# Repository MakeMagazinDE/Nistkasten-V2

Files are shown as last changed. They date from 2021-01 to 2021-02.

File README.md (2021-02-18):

GitHub Logo

Maker Media GmbH
*** 

# Nistkasten-V2
mit Infrarot-Kamera und Klimasensor

### Mit diesem Nistkasten beobachten Sie Vögel beim Nestbau und Brüten durch eine Infrarot-Kamera, nehmen Videos und Bilder auf und messen Temperatur und Luftfeuchtigkeit im Inneren.

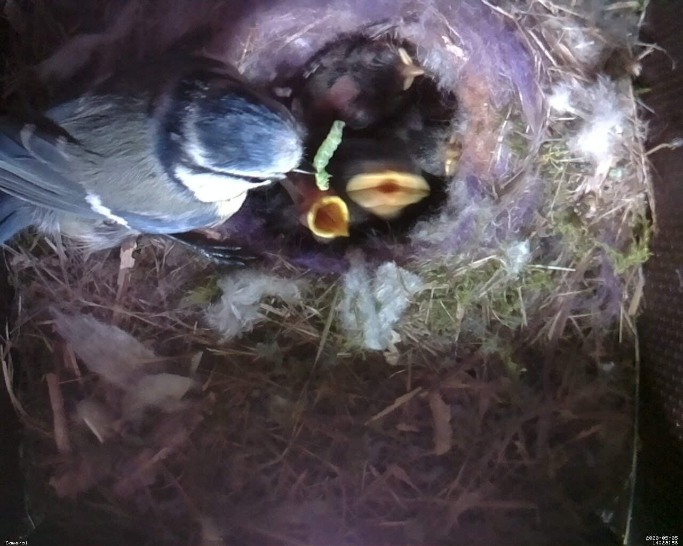
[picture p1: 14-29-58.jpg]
 

Den vollständigen Artikel mit der Bauanleitung gibt es in der **[Make-Ausgabe 1/21 ab Seite 24](https://www.heise.de/select/make/2021/1/2020408465876482831)** zu lesen. 

Lesen Sie bei Problemen bitte die im Ordner [Hinweise](https://github.com/MakeMagazinDE/Nistkasten-V2/blob/main/Hinweise/Problembehebung.md) gespeicherten Dateien.

Achtung: Unter [Software](https://github.com/MakeMagazinDE/Nistkasten-V2/blob/main/Software/Installationsbefehle.txt) finden Sie die Datei mit den Installationsbefehlen. Diese Befehle können Sie per Kopieren und Einfügen zeilenweise übernehmen und vom Raspberry abarbeiten lassen. So vermeiden Sie Mißverständnisse mit Zeilen, die im Magazin wegen Überlänge umgebrochen wurden.

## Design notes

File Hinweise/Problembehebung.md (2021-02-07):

Sollte der Raspberry Zero nach kurzer Zeit kein Kamerabild mehr liefern oder ständig neu booten oder ist das gezeigte Bild überbelichtet,
dann leuchten die IR-LEDs zu stark und nehmen zuviel Strom auf. Wird hingegen bei Tageslicht das Bild des Nestkasten-Inneren plötzlich schwarz, schalten die LEDs zu früh ab.
In beiden Fällen müssen Sie die LEDs mit den Trimmer auf ihren Platinen eingestellen.

Stellen Sie den Trimmer einer der beiden LED so ein, dass sie auch bei völliger Dunkelheit (zugehaltenem Lichtsensor) nicht einschaltet. 
Das Einschalten kann man an einem schwachen roten Glimmen erkennen.

Den Trimmer der anderen LED stellen Sie so ein, dass die LED bei normaler Tageslicht-Zimmerbeleuchtung und offenem Lichtsensor eingeschaltet ist und daher schwach rot glimmt.

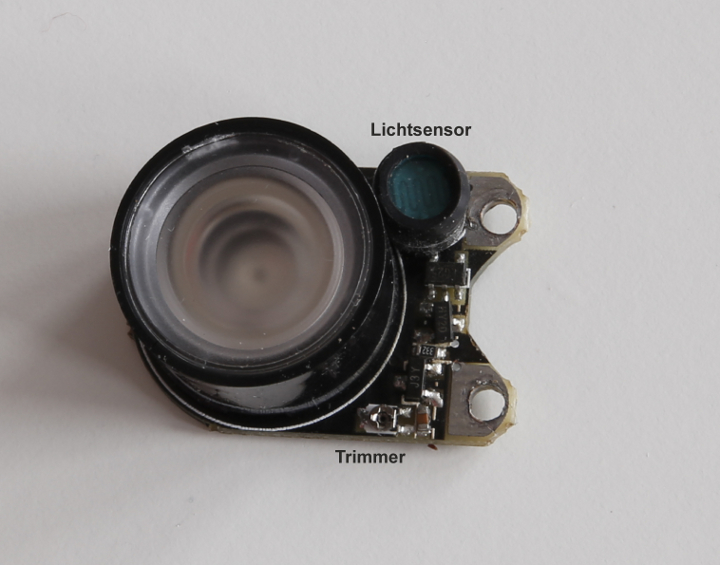
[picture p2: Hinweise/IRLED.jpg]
 

Booten Sie danach den Raspberry erneut, da sich beim Bootvorgang die Kamera auf die Lichtverhaltnisse einstellt.

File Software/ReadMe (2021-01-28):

Befehle bitte einzeln per Copy & Paste in die Konsole übertragen und ausführen.

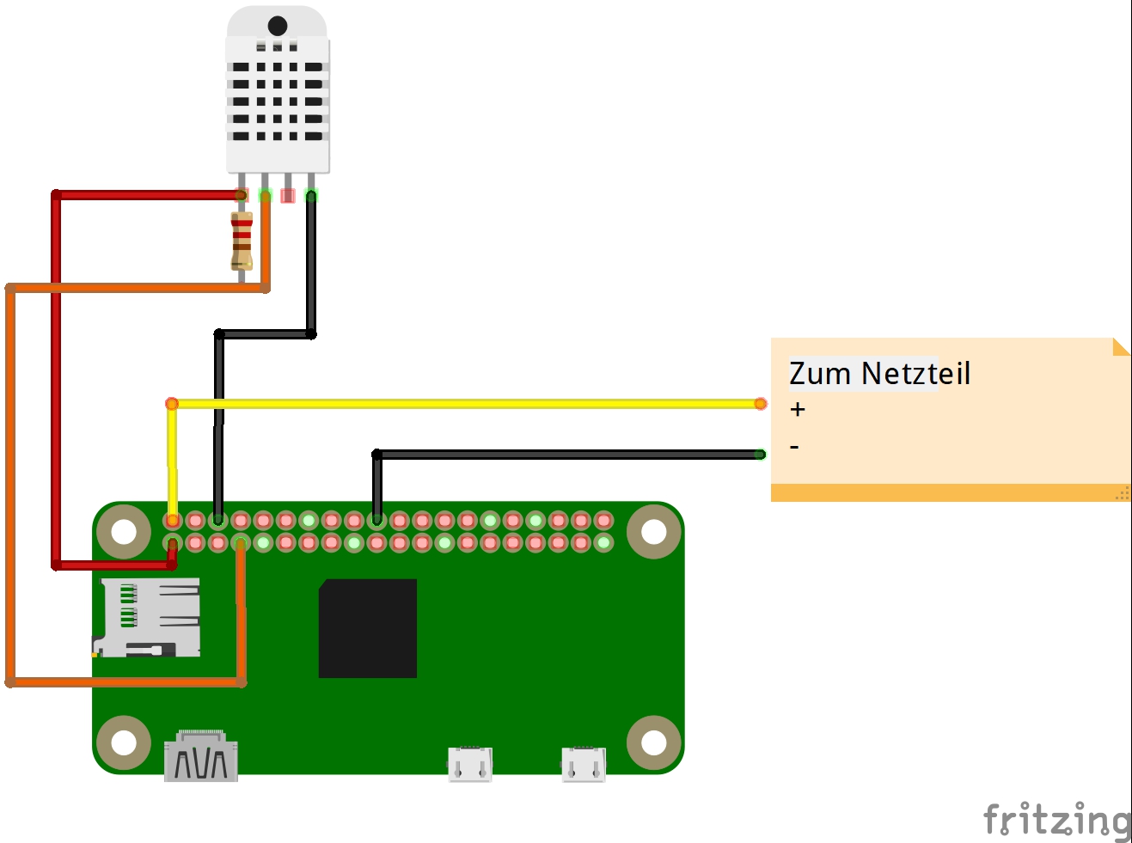
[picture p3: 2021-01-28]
Schaltplan/NistkastenV2.jpg

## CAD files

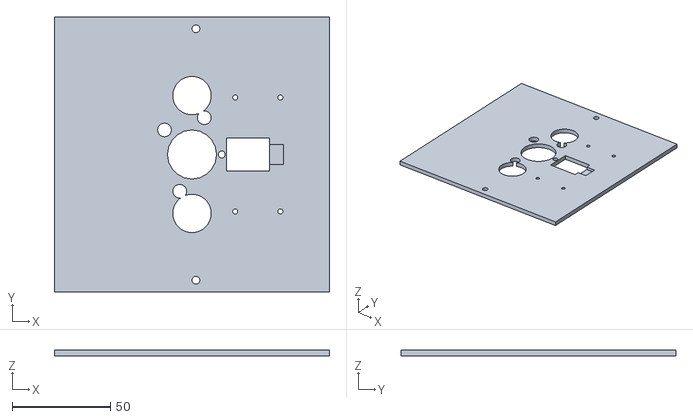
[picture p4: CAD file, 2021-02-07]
Konstruktionsdateien/Nistkasten_Platte.stl
140.0 x 140.0 x 3.00

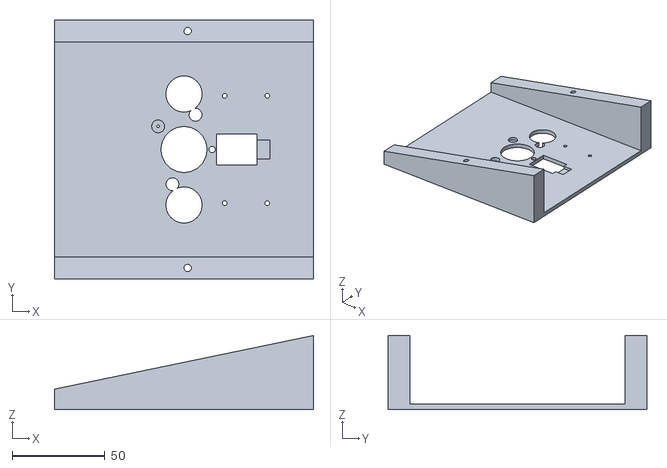
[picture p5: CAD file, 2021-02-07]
Konstruktionsdateien/Nistkasten.stl
140.0 x 140.0 x 40.0

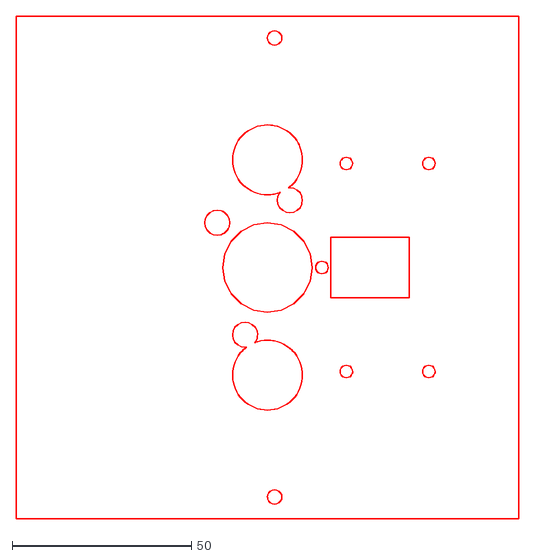
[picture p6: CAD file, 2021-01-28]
Konstruktionsdateien/Zeichnung-1.dxf
140.0 x 140.0

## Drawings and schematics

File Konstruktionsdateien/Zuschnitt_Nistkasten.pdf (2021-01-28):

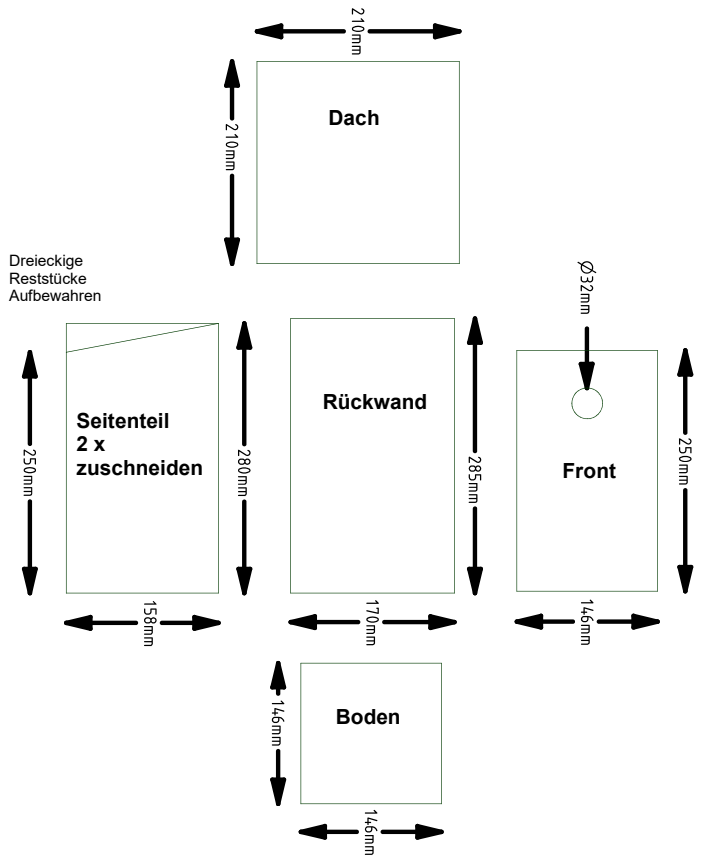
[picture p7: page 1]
Dach; Seitenteil 2 x; zuschneiden; Front; Rückwand; Boden; Dreieckige Reststücke Aufbewahren

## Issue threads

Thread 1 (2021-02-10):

Wrong command

schaeuzerle, 2021-02-10:
https://github.com/MakeMagazinDE/Nistkasten-V2/blob/7462c97816c53f3762aeb029a878e4779167e04f/Software/Installationsbefehle.txt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

should be
`cp /usr/local/share/motioneye/extra/motioneye.systemd-unit-local /etc/systemd/system/motioneye.service`

MasterPMax, 2021-03-02:
Hallo,
ich habe ebenfalls ein Problem bei der Installation der Software.

Nach dem Befehl bekomme ich folgende Fehlermeldung:

```
pi@raspberrypi:~ $ sudo mkdir -p /etc/motioneye
pi@raspberrypi:~ $ sudo cp /usr/local/share/motioneye/extra/motioneye.conf.sample /etc/motioneye/mot                          ioneye.conf
cp: cannot stat '/usr/local/share/motioneye/extra/motioneye.conf.sample': No such file or directory
pi@raspberrypi:~ $ sudo mkdir -p /var/lib/motioneye
pi@raspberrypi:~ $ sudo cp /usr/local/share/motioneye.systemd-unit-local /etc/systemd/system/motioneye.service
cp: cannot stat '/usr/local/share/motioneye.systemd-unit-local': No such file or directory
pi@raspberrypi:~ $ sudo cp /usr/local/share/motioneye/extra/motioneye.systemd-unit-local /etc/systemd/system/motioneye.service
cp: cannot stat '/usr/local/share/motioneye/extra/motioneye.systemd-unit-local': No such file or directory
```
Ich habe auch schon den korrigierten Befehl von oben probiert, ebenfalls ohne Erfolg.
Kann mir hier jemand weiterhelfen?
Vielen Dank!

Gruß MasterPMax

torth, 2021-03-02:
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

hi, ist das Verzeichnis /usr/local/share/motioneye überhaupt vorhanden, oder ist eventuell der Befehl "sudo pip install motioneye" mit einem "_Killed_" abgebrochen? Falls dies zutreffen sollte, dann führe folgenden Befehl aus und mache danach normal weiter:

**_sudo apt-get install python-pillow_**

MasterPMax, 2021-03-02:
Hy,
vielen Dank das wars! Der letzte Punkt collecting pillow war tatsächlich mit Killed abgebrochen.
Jetzt klappt es auch!

noworrries, 2021-03-14:
Selbes Problem, da das "killed" ohne Trennzeichen in der letzten Zeile angefügt wirt, hatte ich es übersehen.
Eine Alternative ist die Installation über
`sudo pip --no-cache-dir install motioneye`
Danke

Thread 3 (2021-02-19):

Platte

charligel, 2021-02-19:
Kann es sein, dass die Aussparungen für die Helligkeitssenoren auf der 3D-Druck-Platte mit Abstand Deckeö verkehrt angebracht sind und damit eine Montage nicht möglich ist?

steffenknott, 2021-02-21:
Ja, das kann ich bestätigen. Ich habe versuchsweise im Slicer das Modell gespiegelt und neu gedruckt, das scheint zu funktionieren.

schaeuzerle, 2021-02-21:
Ja, ist mir auch aufgefallen, nachdem ich es gedruckt habe... Hab einen Fork erstellt, darin liegt nun ein gespiegeltes STL, leicht verschobener Kameraposition und Halterung für einen Raspberry 3B, wenn jemand Interesse hat

Lumixnick, 2021-03-01:
Hallo ist mir auch aufgefallen und ich hab sie kurzerhand umdesigned.
Hier meine STL von gerade. Hoffe ich hab mich nirgends vermessen, meine RasPI liegt auch einfach flach auf, benötige keinen USB-HUB.
[Nistkasten v2_gespiegelt.zip](https://github.com/MakeMagazinDE/Nistkasten-V2/files/6063810/Nistkasten.v2_gespiegelt.zip)

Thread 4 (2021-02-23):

IR-Beleuchtung

avanc, 2021-02-23:
Kann es sein, dass es zwingend notwendig ist, dass der Innenraum dunkel ist?
Ich habe einen Nistkasten in Kiefer aufgebaut. und auch wenn nur eine IR-LED aktiv ist, ist das Bild überbelichtet weiß...

Ich bin mir nicht sicher, ob ich die Sensoren richtig verstanden habe. Wenn ich den Sensor an der Kamera verdecke, hätte ich das Klacken des Filters erwartet und das das Bild dann rötlich ist. Jedoch passiert dies nicht. Nur im Kasten kalckert der Filter hin und her. Jedoch mit dem Problem der Überbelichtung...

torth, 2021-03-19:
hallo zusammen,
kann mir jemand einen Tipp geben, wie ich die IR-LED am besten einstellen kann? Der Trimmregler hat gefühlt in beide Richtungen keinen Anschlag. Eine LED habe ich wie in der Problembeschreibung, zunächst den Sensor zugehalten und dann getrimmt dass die IR-LED nicht angeht. Bei der zweiten ist es so, dass die IR-LED schwach leuchtet, auch bei Tageslicht aber im Nistenkasten dann nach 20 Sek. doch ausgeht und das Kamerabild schwarz wird. Haben die beiden Regler der IR-Leuchten einen Anschlag oder dreht man solange bis es hoffentlich irgendwie passt?

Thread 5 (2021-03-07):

Zuschnitt Nistkasten pdf

noworrries, 2021-03-07:
Maße für die Bodenplatte und Front sind durch einen Zahlendreher zu klein.

Breite Rückwand - 2 x Plattendicke ist 164mm, nicht 146mm

Wer blindlings sägt, sägt 2x.

cyrix2000, 2021-03-08:
Die Plattendicke ist doch 12mm, 170mm - 2x12mm = 146mm. Das stimmt dann doch eigentlich, oder?

noworrries, 2021-03-08:
Bei mir im Printartikel wurden 3 mm gedruckt... auch wenn ich für meine eigene Planung 10-12 mm annahm.

OK hatte das Sperrholz 3mm als Außenwand interpretiert, als ich auf der Zeichnung keine Stärke gefunden hatte und schnell bei der Materialliste geschaut habe.
Die Siebdruckplatte hatte ich gar nicht gesehen...
der identische Verweis auf die „Download-Zeichnung“ tat das übrige.
Zusammen mit 170-(2x3) = 164 ...

Hast recht.

Gruß
Flo

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

cyrix2000, 2021-03-09:
Ich habe eine CAD Datei (step) fuer die Holzelemente erstellt und per fork (plus pull request) hochgeladen.

Closed 2021-03-08.

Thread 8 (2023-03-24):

Funktioniert nur mit Rasbian Buster

ronau, 2023-03-24:
Ich bin der Anleitung [Nistkasten 2.0](https://www.heise.de/select/make/2021/1/2020408465876482831) gefolgt, nachdem diese vor wenigen Tagen noch einmal in [dieser News mit Video](https://www.heise.de/news/Warum-jeder-Maker-JETZT-einen-Nistkasten-bauen-sollte-7549536.html) beworben wurde.

Aber Achtung!
Die Installationsanweisungen in [main/Software/Installationsbefehle.txt](../blob/main/Software/Installationsbefehle.txt) (bzw. im Make-Artikel) funktionieren nur mit **Raspbian Buster**.
Mit der aktuellen Version von Raspbian (Bullseye) wurde das Kamerasystem umgestellt: https://www.raspberrypi.com/news/bullseye-camera-system/
Kameras mit Flachbandkabel (so wie in der Anleitung) werden dann nicht mehr von motionEye gefunden. USB-Kameras würden theoretisch noch funktionieren.

Man muss beim Erstellen der SD-Karte also darauf achten, dass man Raspbian Buster aufspielt. Das geht sogar auch mit dem RPi Image, man muss nur den richtigen Eintrag unter `Raspberry Pi OS (other)` auswählen:

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

Ich könnte mir vorstellen, dass so einige, die jetzt den Nistkasten bauen wollen, an diesem Problem hängenbleiben.
Eventuell sollte das in der News bzw. in der Anleitung aktualisiert werden.

nsauter, 2023-04-28:
Hi! Welche Cam hast du genommen? Ich hab das Teil einmal gebaut und es funktioniert immer noch. Jetzt will ich ein zweiten aber die CAM wir in Motioneye nie geladen. Auch nicht mit Buster. Raspistill etc. liefert aber n Bild. Mit welcher klappt es bei dir?

ronau, 2023-05-01:
Ich hab die MakerHawk IR fisheye, genau wie in der Anleitung [Nistkasten 2.0](https://www.heise.de/select/make/2021/1/2020408465876482831) beschrieben. Hab im motionEye auch wie in Bild 12 beschrieben als Camera Type `Local MMAL Camera` ausgewählt.

Hier meine Settings:
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
